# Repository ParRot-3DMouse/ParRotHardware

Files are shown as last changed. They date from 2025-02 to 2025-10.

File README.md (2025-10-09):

## 目次

- [目次](#目次)
- [必要なもの](#必要なもの)
  - [基板](#基板)
  - [3D プリンタ造形部品](#3d-プリンタ造形部品)
  - [実装する部品（電子部品など）](#実装する部品電子部品など)
  - [ケーブル](#ケーブル)
  - [使用する部品（機構部品など）](#使用する部品機構部品など)
  - [そのほか必要なもの](#そのほか必要なもの)
  - [工具](#工具)
- [本体の作成](#本体の作成)
  - [ケーブル加工](#ケーブル加工)
  - [3D プリント造形部品の追加加工](#3d-プリント造形部品の追加加工)
  - [基板のはんだ付け](#基板のはんだ付け)
    - [センサモジュール基板](#センサモジュール基板)
    - [メイン基板](#メイン基板)
    - [サイドキーパッド基板](#サイドキーパッド基板)
    - [親指モジュール基板](#親指モジュール基板)
    - [OLED モジュール基板](#oled-モジュール基板)
    - [追加キーパッドモジュール基板](#追加キーパッドモジュール基板)
    - [メイン基板とサイドキーパッド基板の配線](#メイン基板とサイドキーパッド基板の配線)
  - [組み立て](#組み立て)

## 必要なもの

### 基板

| 名前 | 数  | データへのリンク |
| :--- | :-: | :---: |
| メイン基板 |  1  |  [こちら](https://github.com/ParRot-3DMouse/ParRotHardware/tree/main/1.0/PCB/main)  |
| センサモジュール基板 |  1  | [こちら](https://github.com/ParRot-3DMouse/ParRotHardware/tree/main/1.0/PCB/sensor) |
| サイドキーパッド基板 |  1  |  [こちら](https://github.com/ParRot-3DMouse/ParRotHardware/tree/main/1.0/PCB/side)  |
| OLED モジュール基板 |  1  |  [こちら](https://github.com/ParRot-3DMouse/ParRotHardware/tree/main/1.0/PCB/OLED)  |
| 親指モジュール基板 |  1  | [こちら](https://github.com/ParRot-3DMouse/ParRotHardware/tree/main/1.0/PCB/thumb)  |
| 追加キーパッドモジュール基板 |  1  | [こちら](https://github.com/ParRot-3DMouse/ParRotHardware/tree/main/1.0/PCB/extra)  |

### 3D プリンタ造形部品

| 名前 | 数  | ファイル名 |
| :--- | :-: | :--- |
| 本体底面部 |  1  | bottom.step |
| 本体カバー |  1  | body_cover.step |
| debug カバー |  1  | debug_cover.step |
| OLED モジュールカバー |  1  | OLED_cover.step |
| 親指モジュールカバー |  1  | SW_cover.step |
| ボール保持部 |  1  | ball_holder.step |
| ボール保持部カバー |  1  | ball_holder_cover.step  |
| 追加キーパッドモジュール底面部 |  1  | side_bottom.step |
| 追加キーパッドモジュールカバー |  1  | side_cover.step |
| 親指部キーキャップ 1 |  1  | thumb_keycap1.step |
| 親指部キーキャップ 2 |  1  | thumb_keycap1.step |
| ジョイント |  2  | jount.step |
| (はんだ付け用治具 1) |  1  | はんだ付け用治具 1.step |
| (はんだ付け用治具 2) |  1  | はんだ付け用治具 2.step |

- はんだ付け用治具1,2はメイン基板とサイドキーパッド基板のはんだ付けの際のみに使用します。

### 実装する部品（電子部品など）

| 名前 | 概要 | 数 | 主な調達先 |
| :--- | :--- | :--- | :--- |
| PMW3360 | イメージセンサ | 2 | Aliexpress |
| 1n4148w | 表面実装ダイオード | 11 | 秋月 |
| sk6812MINI-E | マイコン内蔵フルカラー LED | 5 | 秋月 |
| Kailh Swich socket(MX) | CherryMX スイッチのソケット | 9 | 遊舎工房 |
| Kailh Swich socket(Choc) | Choc v1 スイッチのソケット | 2 | 遊舎工房 |
| OLED | 128x32pixcel の SSD1306 登載 OLED モジュール | 1 | 遊舎工房 |
| SKRPABE010 | 表面実装スイッチ | 3 | 秋月 |
| S6B-PH-KL | PH コネクタ ベース付ポスト(サイド型)6 極 | 5 | 千石電商 |
| S8B-PH-KL | PH コネクタ ベース付ポスト(サイド型)8 極 | 1 | 千石電商 |
| B6B-PH-KL | PH コネクタ ベース付ポスト(トップ型)6 極 | 1or2 | 秋月 |
| SKS-01 | ジャンパワイヤ(2.54mm) | 6 | Amazon |
| ピンヘッダ | ハウジング高さ 2.5mm，2.54mm ピッチ，4 ピン  | 1 | (秋月) |

- ピンヘッダは多くの場合、OLEDモジュールに付属しています。  
- デバグ用のSDWを引き出す場合、B6B-PH-KLは2つ使用します。逆にSDWを使用しない場合は1つで問題ありません。

### ケーブル

| 名前 | 概要 | 数量  | 主な調達先 |
| :--- | :--- | :-: | :---: |
| PHR-6 | PH コネクタ　ハウジング 6 極 |  6  | 秋月 |
| PHR-8 | PH コネクタ　ハウジング 8 極 |  1  | 秋月 |
| SPH-002T-P0.5L | PH コネクタ コンタクト | 44  | 秋月 |
|電線 | AGW22 ビニル被膜線 | 1m程度|
- 電線はPHコネクタ用コンタクトに適合する太さのものを選択してください。

### 使用する部品（機構部品など）

| 名前 | 概要 | 数  | 主な調達先 |
| :--- | :--- | :-: | :---: |
| M2 インサートナット | 3.5mm x 4mm(直径 x 高さ) | 12  | [Amazon](https://www.amazon.co.jp/dp/B09NNPNGB8) |
| M2 4mm ネジ | |  6  | |
| M2 6mm ネジ | |  2  | |
| M2 8mm ネジ | |  1  | |
| M2 10mm ネジ | |  2  | |
| M2 20mm ネジ | |  1  | |
| M3 8mm ネジ | |  4  | |
| M3 ナット | |  4  | |
| M3 ワッシャ | |  4  | |
| 磁石 | 直径 6mm 厚み 2.5mm のもの |  4  | セリア |
| ゴム足 | 直径 10mm のもの |  7  | [aitendo](https://www.aitendo.com/product/14406) |

- 記載の寸法の部品の入手が難しい場合、3Dプリント部品を編集し、造形物の寸法を調整することで対処してください。

### そのほか必要なもの
| 名前 | 数 | 主な調達先 |
| :--- | :-: | :---: |
| 40mmトラックボール | 1個 | Amazon |
| CherryMx規格のキーキャップ | 6個 | Amazon、遊舎工房 |

### 工具

ParRot を作成する際に使用した工具を次に示します．

- はんだごて一式
- ピンセット
- ニッパー
- ペンチ
- ワイヤーストリッパ
- PHコネクタ用圧着工具
- 精密ドライバーセット
- ピンバイス
- やすり
- 3D プリンタ

消耗品

- はんだ
- ハンダフラックス
- 接着剤
- マスキングテープ

## 本体の作成

### ケーブル加工

使用するケーブルは次の通りです．

| 番号 | ケーブル本数 | 使用するハウジング | 長さ | 向き |
| :--- | :--- | :--- | :--- | :--- |
| 1 | 6 | 6P | 13mm | 逆 |
| 2 | 6 | 6P | 25mm | 逆 |
| 3 | 6 | 6P | 30mm | 順 |
| 4 | 5 | 8P | 80mm | ー |

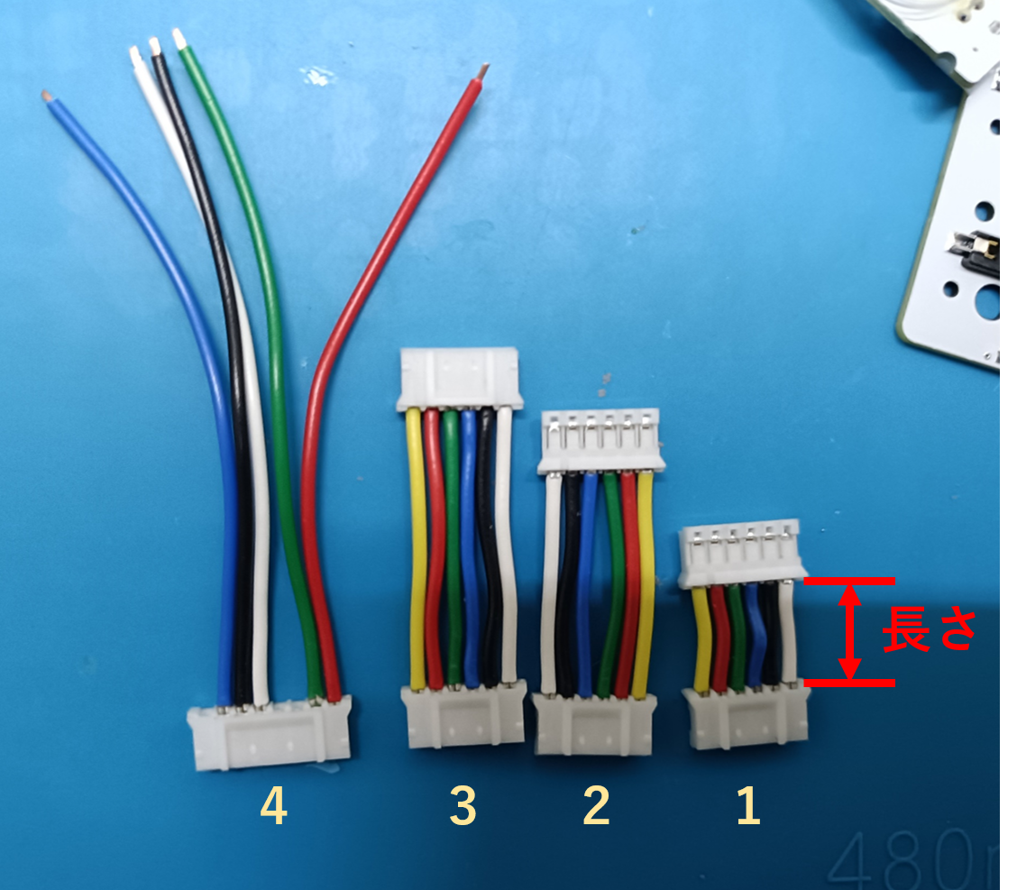
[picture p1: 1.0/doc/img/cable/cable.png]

4 について
コンタクトが見える側で ↓ のようにケーブルを差し込んでください．  
|o|o|-|-|o|o|o|-|

### 3D プリント造形部品の追加加工

必要であればお使いの3Dプリンタに合わせてモデルの各種寸法は元となるstepファイルを編集し、適宜調整してください。
事前にサポート材をすべて除去してください．
また，ピンバイス等を用いてネジを通す穴をネジが通るように加工してください．

1. インサートナットを熱圧入します．
   本体底面部においては次の 8 箇所にインサートナットを圧入します．  
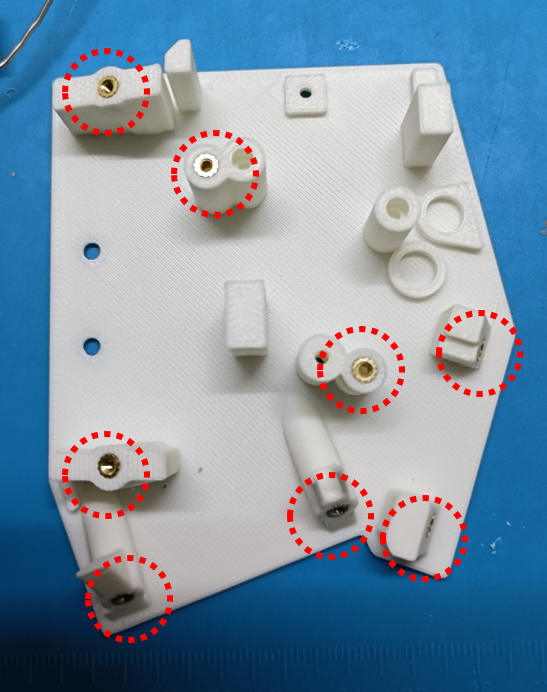
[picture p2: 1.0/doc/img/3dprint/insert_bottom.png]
本体底面部インサートナット
     
   本体カバーにおいては次の 1 箇所にインサートナットを圧入します．  
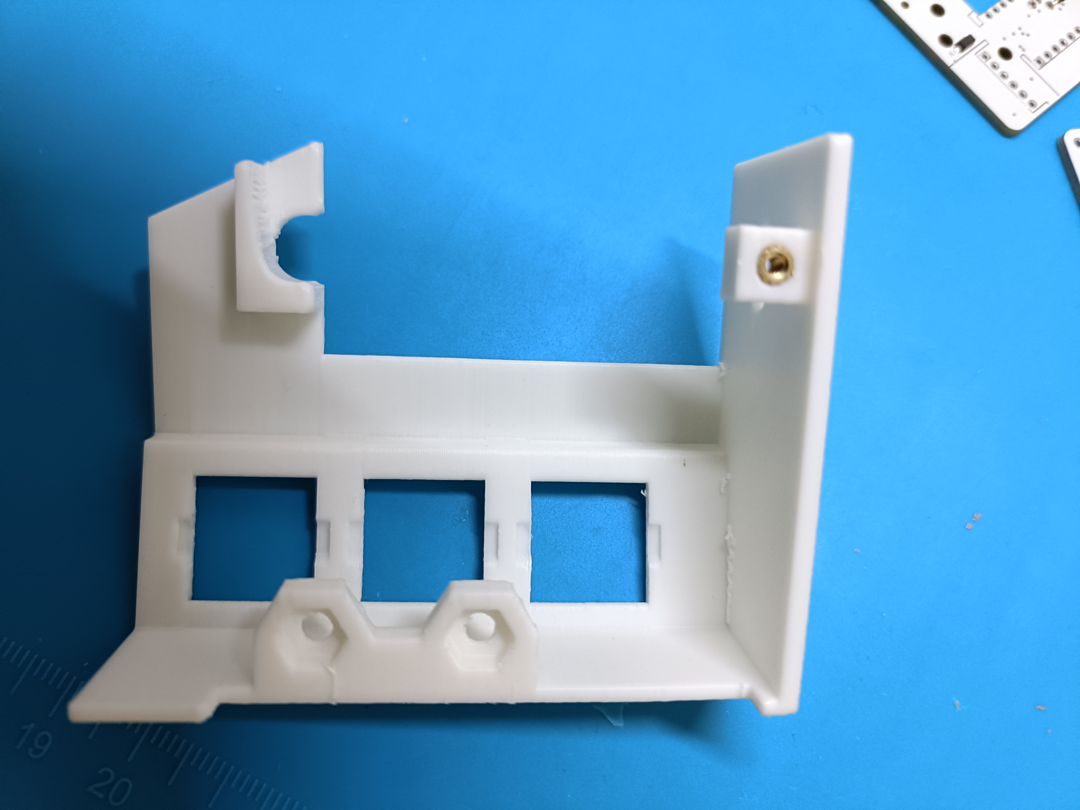
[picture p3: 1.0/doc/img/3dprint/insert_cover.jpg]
本体カバーインサートナット
     
   ボール保持部においては次の 2 箇所にインサートナットを圧入します．  
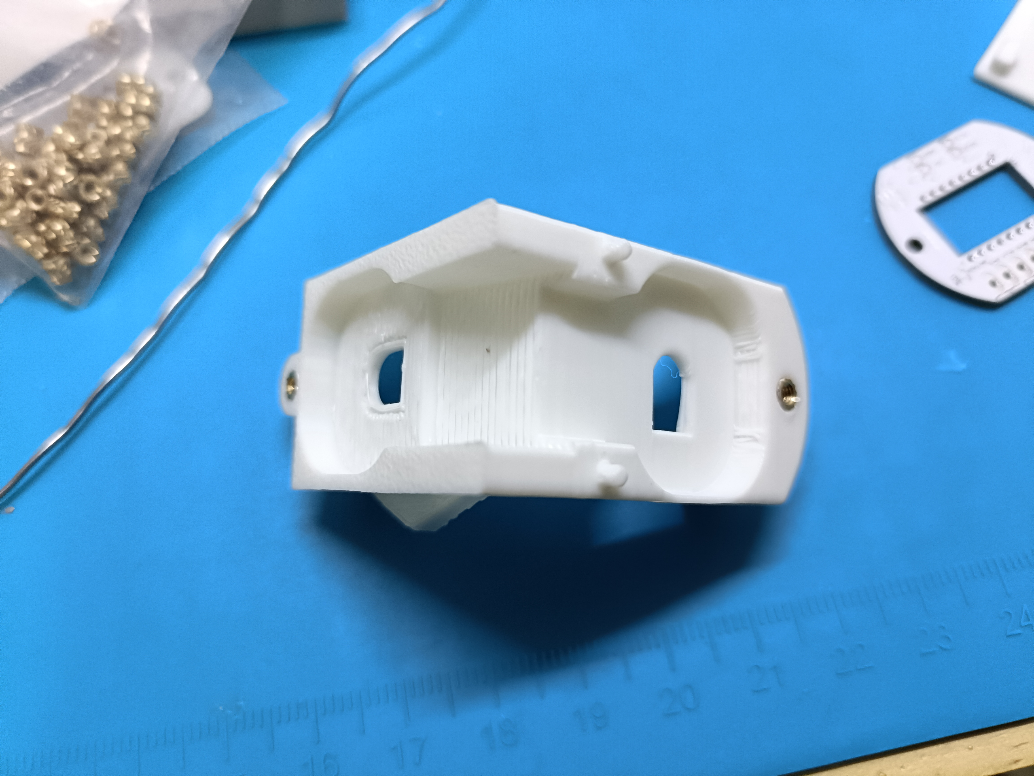
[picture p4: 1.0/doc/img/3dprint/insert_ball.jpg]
ボール保持部インサートナット
     
   追加キーパッドモジュール底面部においては次の 2 箇所にインサートナットを圧入します．  
   追加キーパッドモジュール底面部インサートナット
2. 磁石を接着します．
   本体底面部において，次の二か所に磁石を接着します．
   接着剤を穴の底面と側面に塗布し，磁石を接着します．
   この際に，二つの磁石の極が異なるように配置してください．  
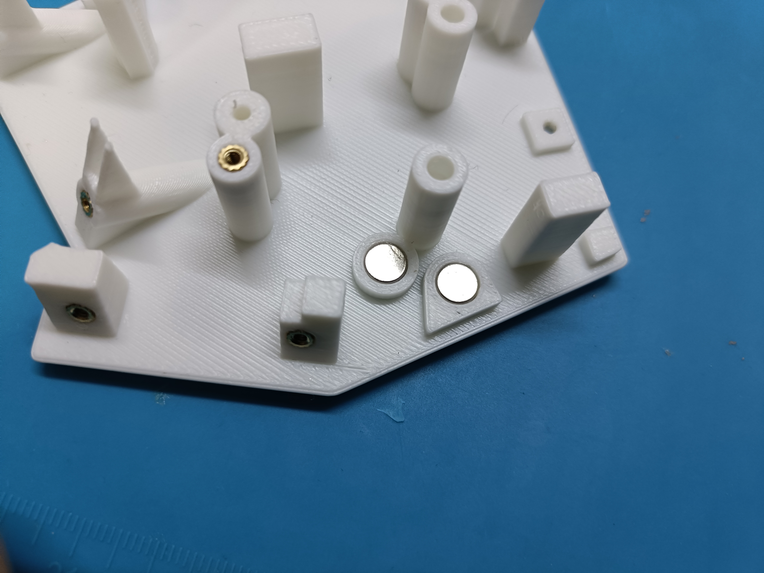
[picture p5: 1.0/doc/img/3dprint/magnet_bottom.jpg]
本体底面部磁石
   

debug カバーにおいて次の二か所に磁石を接着します．
この際に，本体底面部と引き合う向きで磁石を接着します．
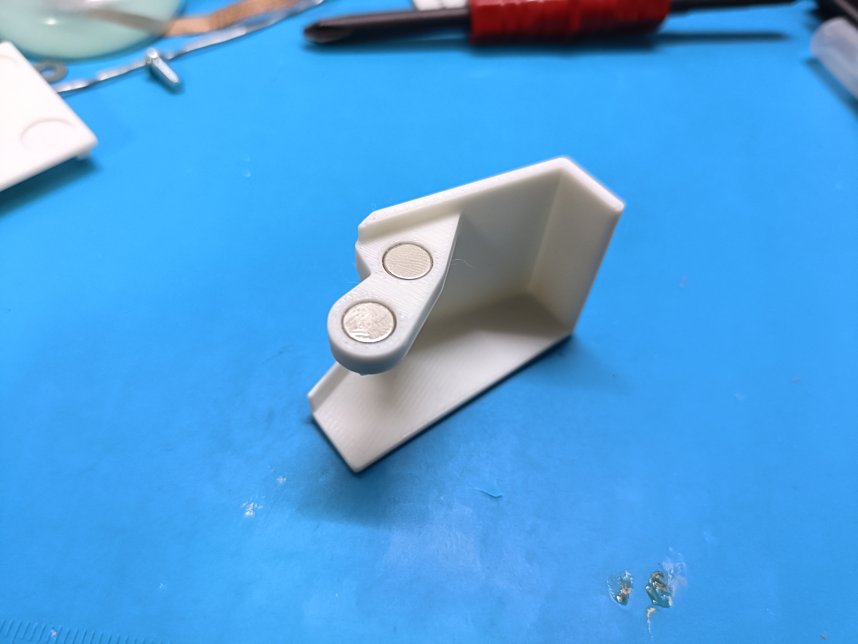
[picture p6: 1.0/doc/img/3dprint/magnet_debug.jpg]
debugカバー磁石


3. ゴム足を取り付けます．
   本体底面部，追加キーパッドモジュール底面部にゴム足を接着します．
   くぼみがあるところにゴム足を接着します．
   ゴム足がはがれることが多かったので接着剤を使用することを推奨します．
   本体底面部ゴム足
   追加キーパッドモジュール底面部ゴム足

### 基板のはんだ付け

#### センサモジュール基板

表面  
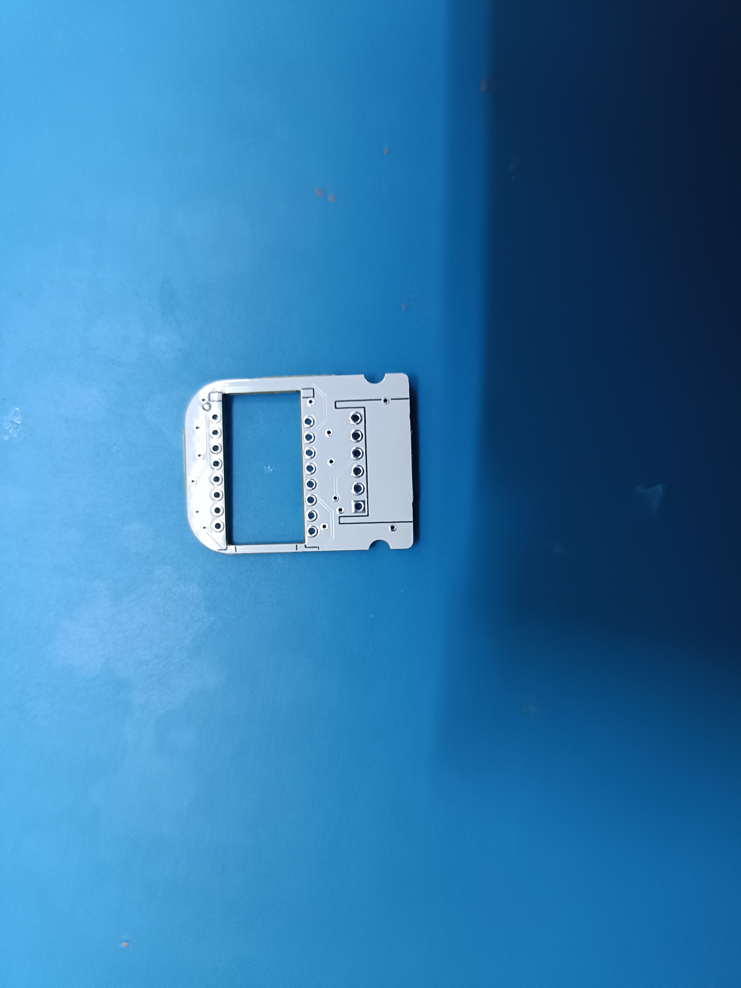
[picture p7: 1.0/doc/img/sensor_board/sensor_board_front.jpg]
センサ基板表面
  
裏面  
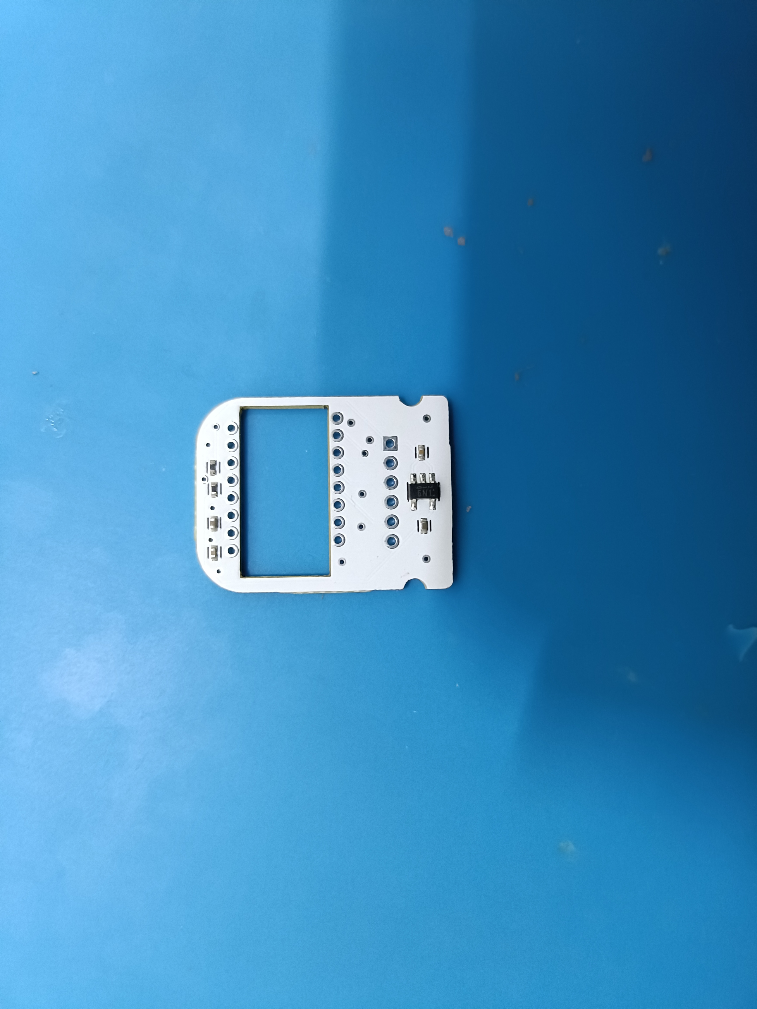
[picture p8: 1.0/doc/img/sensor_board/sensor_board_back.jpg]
センサ基板裏面


センサ基板に実装する部品は次の通りです．

| 名前 | 概要 | 数  |
| :--- | :--- | :-- |
| PMW3360 | イメージセンサ | 1 |
| S6B-PH-KL | PH コネクタ ベース付ポスト(サイド型)6 極 | 1 |

1. PMW3360 の実装
   PMW3360 を実装します．向きに注意してください．正しい向きは．画像を参照してください。裏面からセンサを基板に差し込み，表面ではんだ付けします．  
   センサ基板PMW3360実装裏  
   センサ基板PMW3360実装表

2. コネクタの実装
   次に，コネクタを実装します．
   裏面からコネクタを基板に差し込み，表面ではんだ付けします．  
   センサ基板コネクタ実装
3. レンズの取り付け
   PMW3360 のレンズを取り付けます．  
   センサのカプトンテープを剥がし，レンズをセンサに取り付けます．  
   センサ基板レンズ取り付け  
   センサから飛び出ているガイドポスト二か所を半田ごてで溶かし，レンズを固定します．  
   センサ基板レンズ固定

#### メイン基板

表面  
メイン基板表面  
裏面  
メイン基板裏面

メイン基板に実装する部品は次の通りです．

| 名前 | 概要 | 数 |
| :--- | :--- | :----- |
| PMW3360 | イメージセンサ | 1 |
| SKRPABE010 | 表面実装スイッチ | 2 |
| S6B-PH-KL  | PH コネクタ ベース付ポスト(サイド型)6 極 | 2 |
| S8B-PH-KL  | PH コネクタ ベース付ポスト(サイド型)8 極 | 1 |
| B6B-PH-KL  | PH コネクタ ベース付ポスト(トップ型)6 極 | 1 or 2 |

1. スイッチの実装
   Boot スイッチと Reset スイッチを実装します．SKRPABE010 を表面に実装します．  
   メイン基板スイッチ実装

2. PMW3360 の実装
   次に，PMW3360 を実装します．表面で足をはんだ付けします．向きに注意してください．向きを基板裏面のシンボルに合わせます．裏面からセンサを基板に差し込み，表面ではんだ付けします．  
   メイン基板PMW3360実装表  
   メイン基板PMW3360実装裏

3. コネクタの実装
次に，コネクタを実装していきます．  
初めに，センサモジュールとの接続用のコネクタ(S6B-PH-KL)を実装します.
表面からコネクタを基板に差し込み，裏面ではんだ付けします．  
メイン基板センサコネクタ実装  
次に，サイドキーパッドとの接続用のコネクタ(S8B-PH-KL)と OLED モジュールとの接続コネクタ(S6B-PH-KL)を実装します．裏面からコネクタを基板に差し込み，表面ではんだ付けします．  
メイン基板サイドOLEDコネクタ実装  
次に，親指モジュールとの接続用のコネクタ(B6B-PH-KL)を実装します．裏面からコネクタを基板に差し込み，表面ではんだ付けします．  
メイン基板親指コネクタ実装  
任意でデバッグ用のコネクタを実装します．表面からコネクタを基板に差し込み，裏面ではんだ付けします．
<!--
![メイン基板デバグコネクタ実装](1.0/doc/img/main_board/conn_debug.jpg)
-->

4. レンズの取り付け
   センサ基板と同様の手順で PMW3360 のレンズを取り付けます．

#### サイドキーパッド基板

表面  
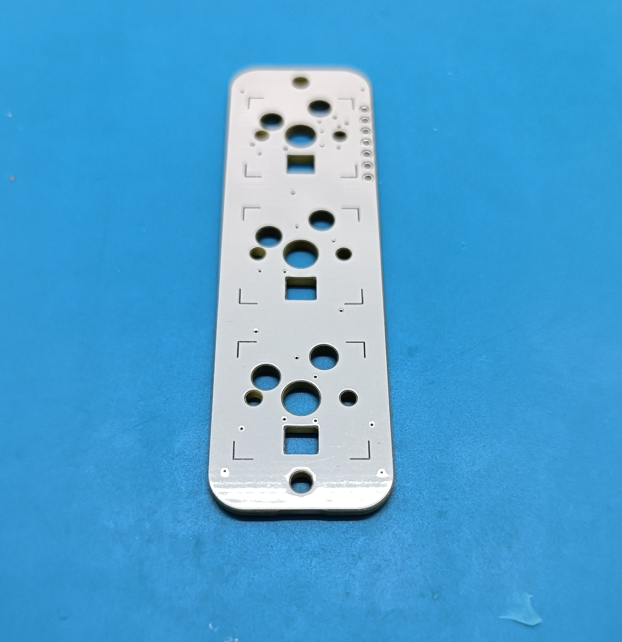
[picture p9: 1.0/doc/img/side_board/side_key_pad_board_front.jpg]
サイドキーパッド基板表面
  
裏面  
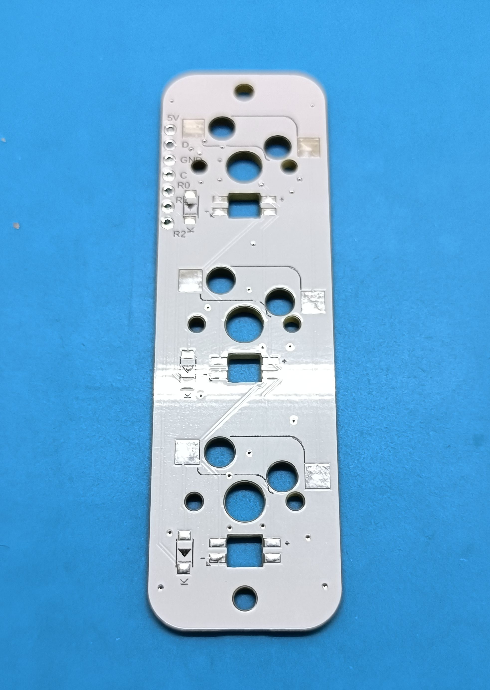
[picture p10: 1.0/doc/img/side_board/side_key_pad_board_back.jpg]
サイドキーパッド基板裏面


実装する部品は次の通りです．
| 名前 | 概要 | 数 |
|:-|:-|:-|
| Kailh Swich socket(MX) | CherryMX スイッチのソケット | 3 |
| sk6812MINI-E | マイコン内蔵フルカラー LED | 3 |
| 1n4148w | 表面実装ダイオード | 3 |

裏面に部品を実装します．
LED,ダイオード，MX ソケットを実装します．LED，ダイオード実装の際には向きに注意してください．正しい向きは画像を参照してください．  
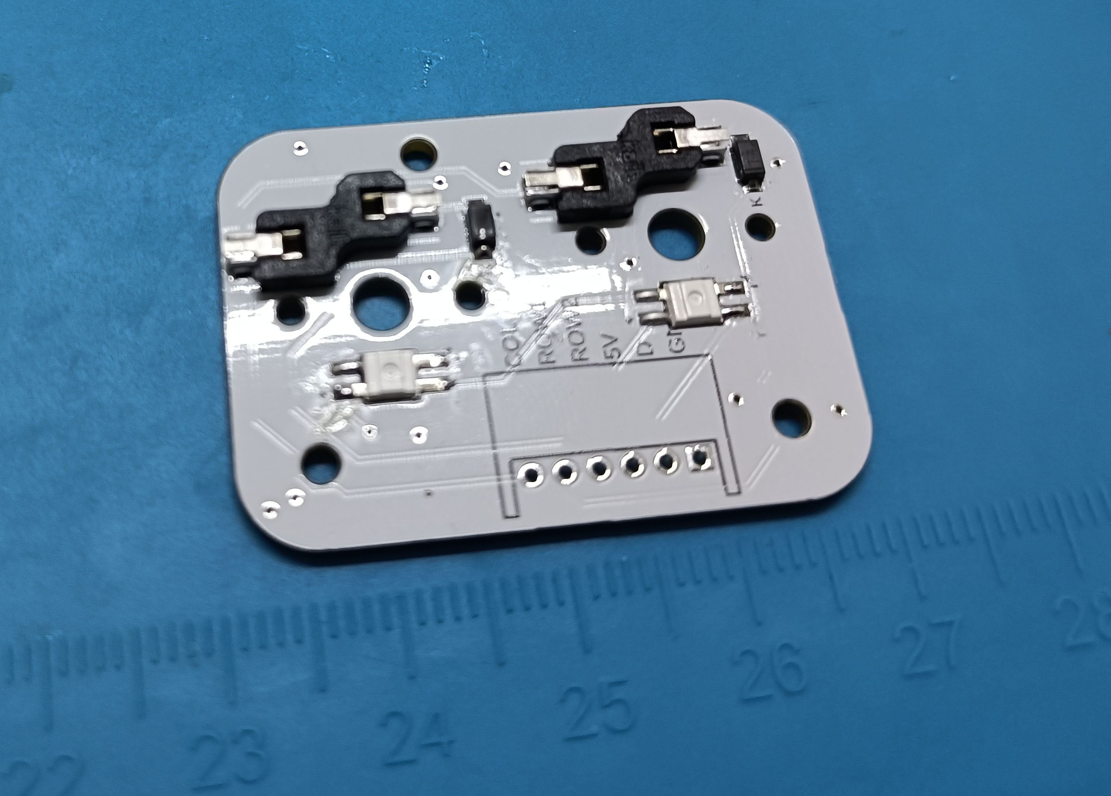
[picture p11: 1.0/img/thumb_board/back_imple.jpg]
サイドキーパッド基板裏面実装
  
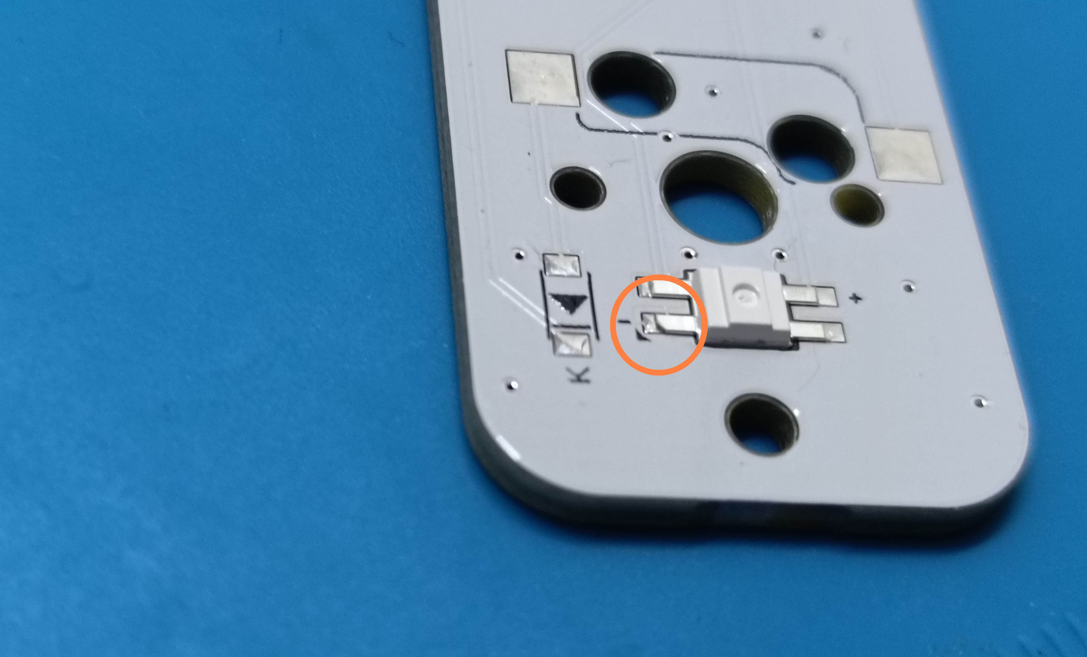
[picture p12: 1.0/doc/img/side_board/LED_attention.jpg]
RGBLED注意
  
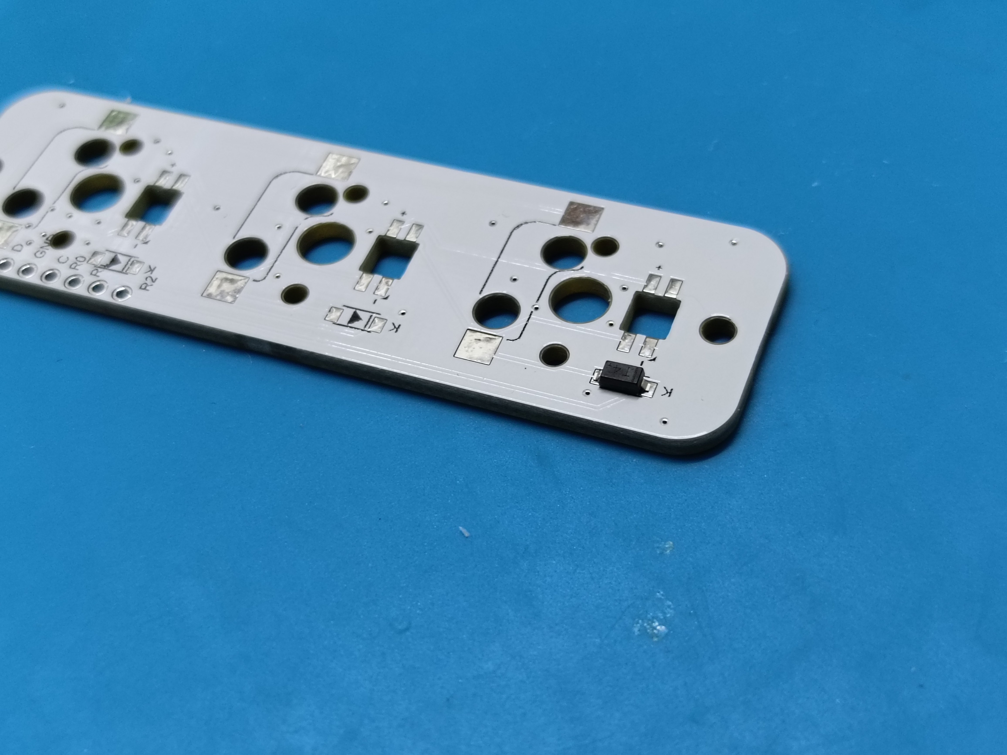
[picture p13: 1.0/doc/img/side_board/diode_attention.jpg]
ダイオード注意


#### 親指モジュール基板

表面  
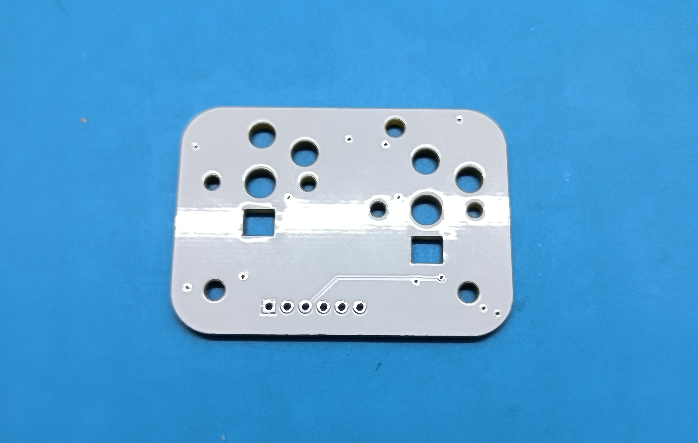
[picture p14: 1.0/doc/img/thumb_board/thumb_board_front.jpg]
親指モジュール基板表面
  
裏面  
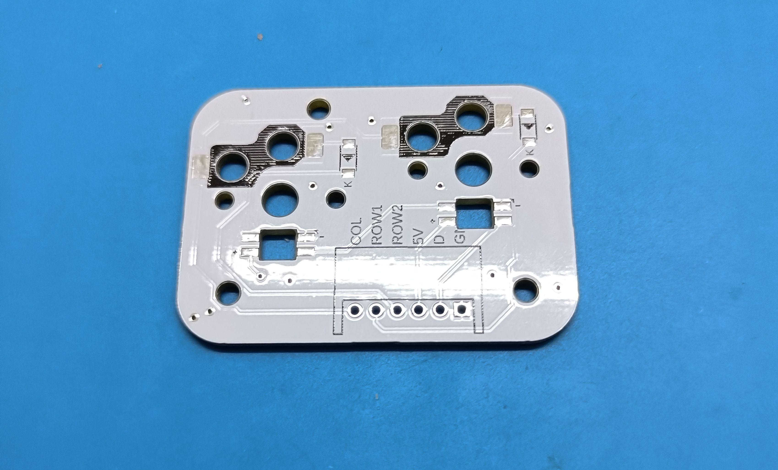
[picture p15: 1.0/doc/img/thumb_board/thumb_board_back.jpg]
親指モジュール基板裏面


実装する部品は次の通りです．
| 名前 | 概要 | 数 |
|:-|:-|:-|
| Kailh Swich socket(Choc) | Kailh_choc v1 スイッチのソケット | 2 |
| sk6812MINI-E | マイコン内蔵フルカラー LED | 2 |
| 1n4148w | 表面実装ダイオード | 2 |
| S6B-PH-KL | PH コネクタ ベース付ポスト(サイド型)6 極 | 1 |

裏面に部品を実装します．
LED,ダイオード，choc ソケットを実装します．choc ソケット，LED，ダイオード実装の際には向きに注意してください．
choc ソケットにも向きがあります．図のように飛び出している部分が外側を向くように実装します．  
親指モジュール基板裏面実装  
RGBLED注意

接続用のコネクタを実装します．裏面からコネクタを基板に差し込み，表面ではんだ付けします．  
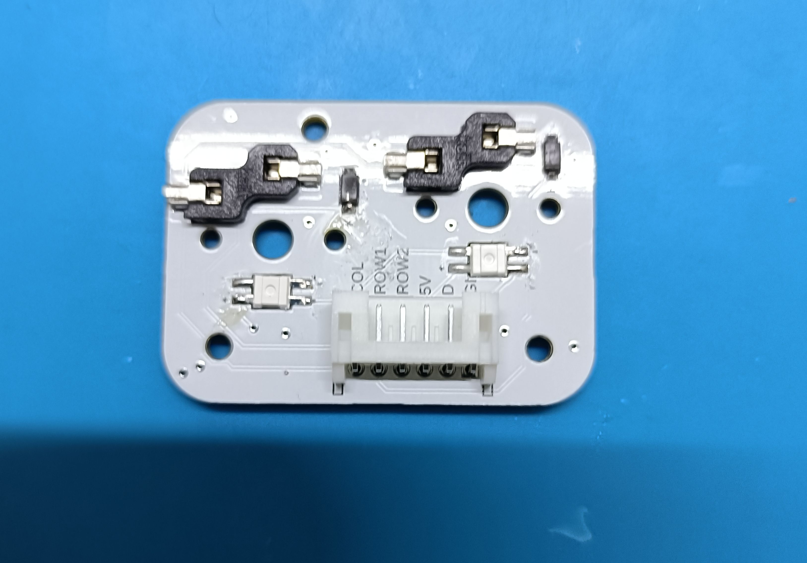
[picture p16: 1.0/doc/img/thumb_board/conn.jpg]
親指モジュール基板コネクタ実装


#### OLED モジュール基板

表面  
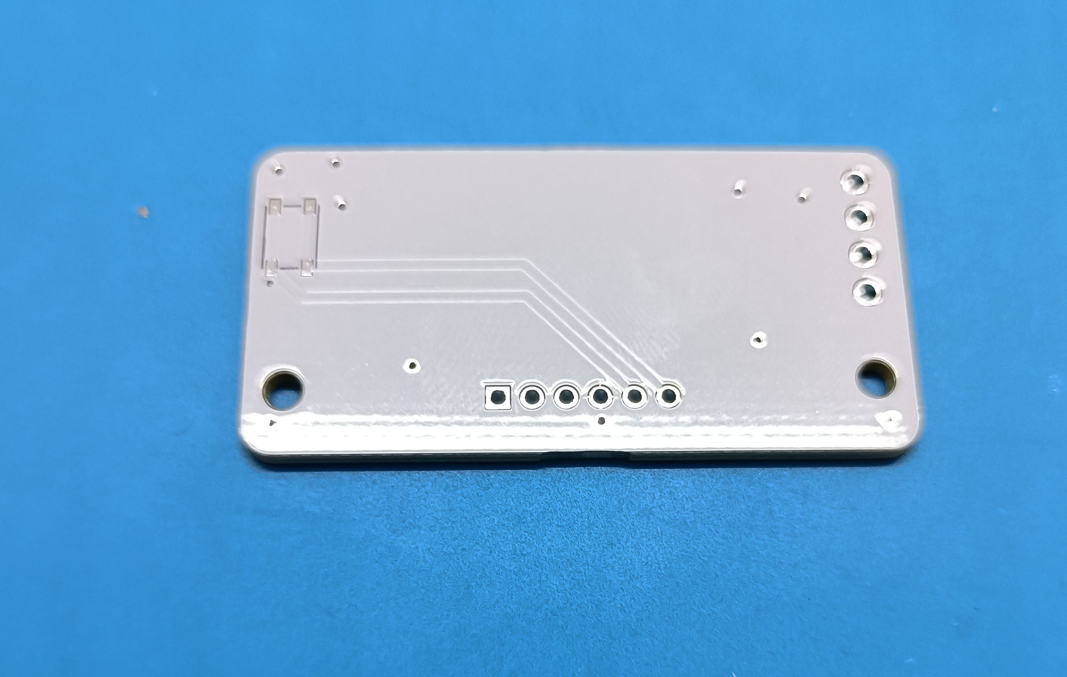
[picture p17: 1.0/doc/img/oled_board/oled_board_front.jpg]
OLEDモジュール基板表面
  
裏面  
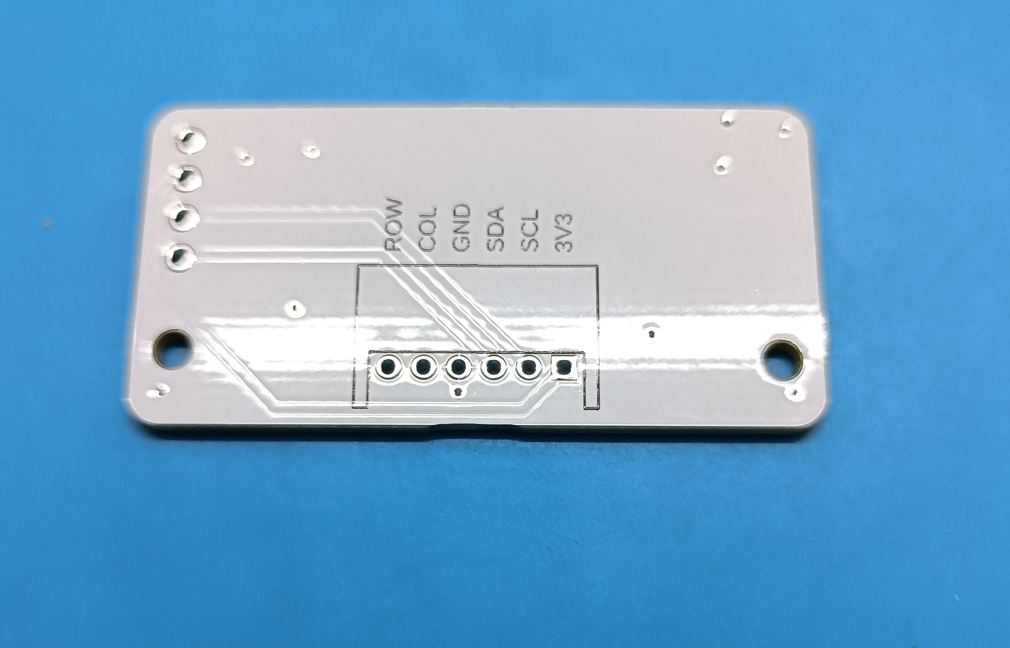
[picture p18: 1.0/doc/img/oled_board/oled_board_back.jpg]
OLEDモジュール基板裏面


実装する部品は次の通りです．
| 名前 | 概要 | 数 |
|:-|:-|:-|
| SKRPABE010 | 表面実装スイッチ | 1 |
| OLED | 128x32pixcel の SSD1306 登載 OLED モジュール| 1 |
| S6B-PH-KL | PH コネクタ ベース付ポスト(サイド型)6 極 | 1 |

1. スイッチの実装
   表面実装スイッチを表面に実装します．  
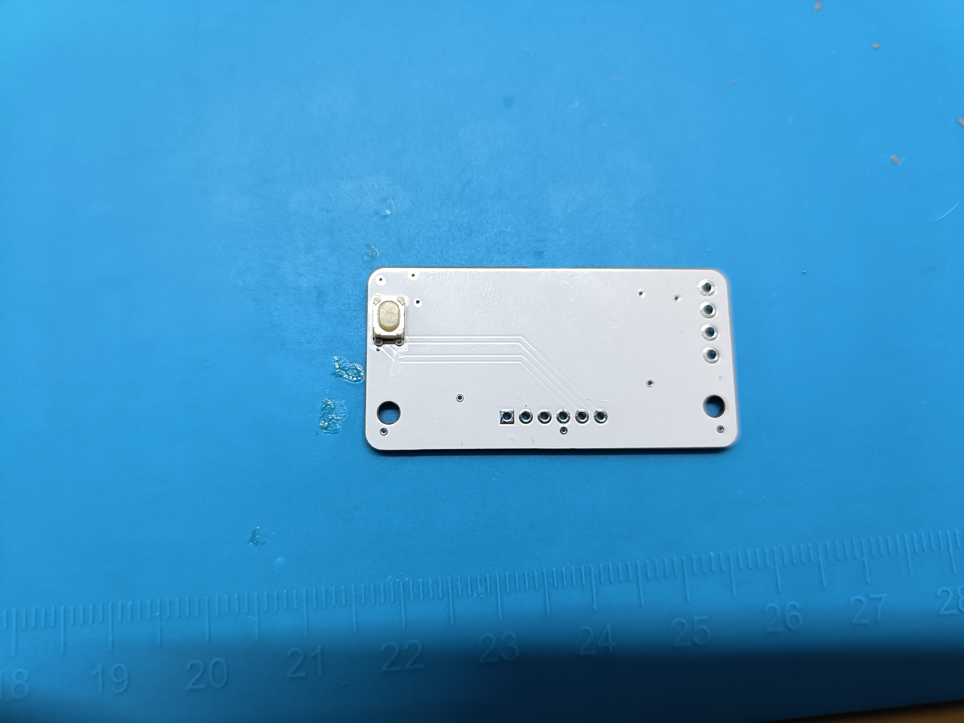
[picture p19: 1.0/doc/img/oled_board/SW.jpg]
OLEDモジュール基板表面実装
   

2. コネクタの実装
   次に，コネクタを実装します．裏面からコネクタを基板に差し込み，表面ではんだ付けします．  
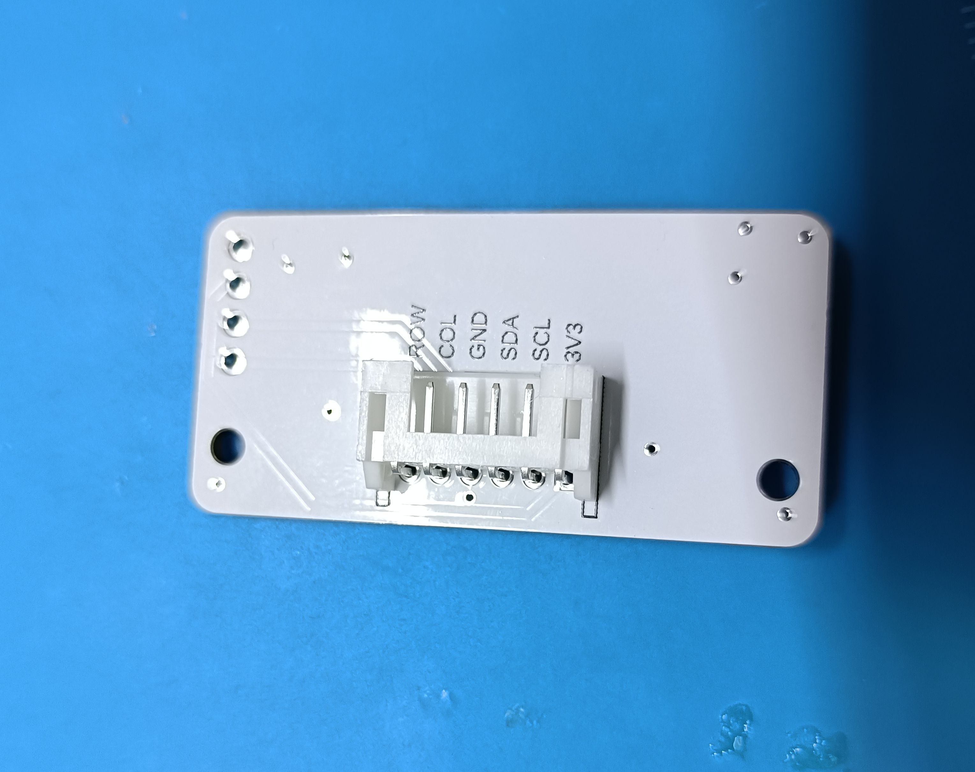
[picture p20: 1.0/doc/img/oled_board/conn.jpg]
OLEDモジュール基板コネクタ実装
   

3. OLED の実装
   次に，OLED を実装します．  
   OLED にピンヘッダをはんだ付けします．  
   OLEDピンヘッダはんだ付け  
   OLED を基板に差し込みます．任意で基板の裏側から出ているピンヘッダを切断します．  
   基板の裏側からピンヘッダをはんだ付けします．この際に基板のエッジと OLED のエッジが平行になるように注意してください．大きくゆがんでいると組み立てた際に OLED の押し込みができなくなる場合があります．  
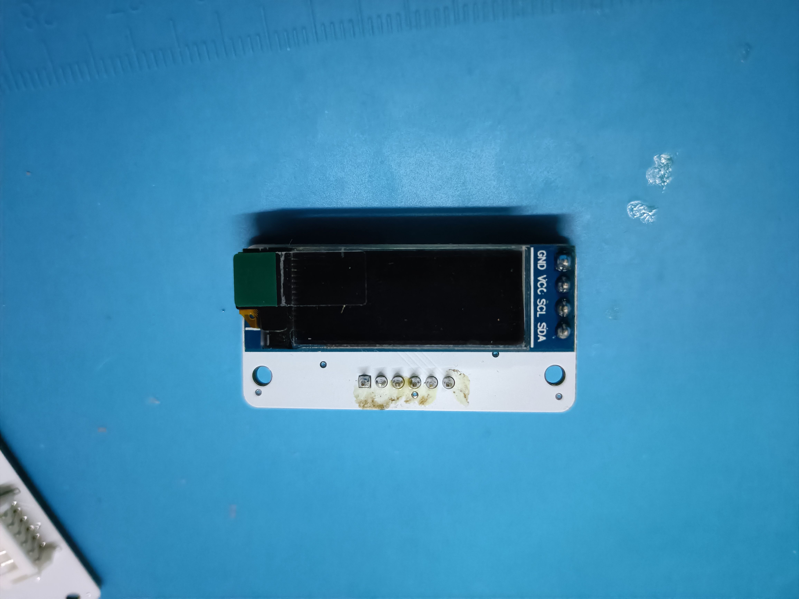
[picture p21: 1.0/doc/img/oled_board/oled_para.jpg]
OLED注意
   

#### 追加キーパッドモジュール基板

表面  
追加キーパッドモジュール基板表面  
裏面  
追加キーパッドモジュール基板裏面

実装する部品は次の通りです．
| 名前 | 概要 | 数 |
|:-|:-|:-|
|| CherryMX スイッチのソケット | 6 |
| 1n4148w | 表面実装ダイオード | 6 |

1. 表面実装部品の実装
   裏面に部品を実装します．
   ダイオード，MX ソケットを実装します．ダイオード実装の際には向きに注意してください．図のように基板のシルクに合わせて実装します．  
   追加キーパッドモジュール基板裏面実装  
   ダイオード注意

2. ケーブルの取り付け
   ケーブル 4 をはんだ付けします．ケーブルの向きに注意してください．ケーブルが外側を向きようにします．また，基板を裏面から見た際にハウジングが見える向きにします．  
   追加キーパッドモジュール基板ケーブル4

ケーブルを反対側に折り曲げます．  
追加キーパッドモジュール基板ケーブル4折り曲げ

#### メイン基板とサイドキーパッド基板の配線

メイン基板とサイドキーパッド基板を接続します．
本体底面部にメイン基板とサイドキーパッド基板を取り付けます．固定には M2 4mm ネジを 4 本使用します．  
メイン基板サイドキーパッド基板取り付け  
ジャンパワイヤを 7 本基板表側から差し込みます．  
メイン基板サイドキーパッド基板配線  
この状態でマスキングテープ等で固定します．  
メイン基板サイドキーパッド基板配線  
メイン基板とサイドキーパッド基板を外し，はんだ付け用治具 1,2 に取り付けます．  
メイン基板サイドキーパッド基板配線  
基板の裏側からジャンパワイヤをはんだ付けします．  
メイン基板サイドキーパッド基板配線  
余分なジャンパワイヤを切断します．  
メイン基板サイドキーパッド基板配線

### 組み立て

追加キーパッドモジュール底面部にジョイントを取り付けます．ねじは M3 8mm ネジを使用します．また，ジョイントの上下を M3 ワッシャで挟み，M3 ナットで締結します．  
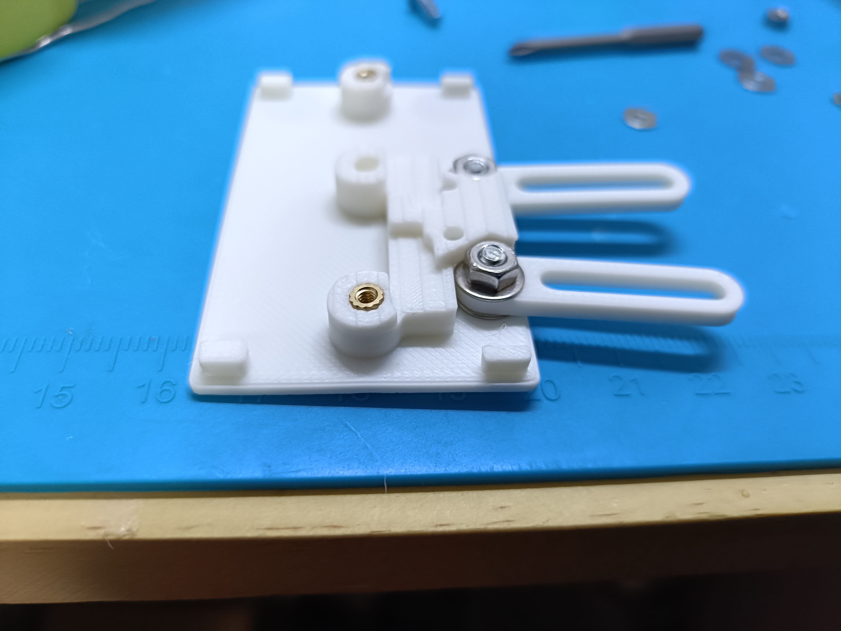
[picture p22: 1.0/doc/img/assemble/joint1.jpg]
  
本体底面部とジョイントを締結します．ねじは M3 8mm ネジを使用します．また，ジョイントの上下を M3 ワッシャで挟み，M3 ナットで締結します．  
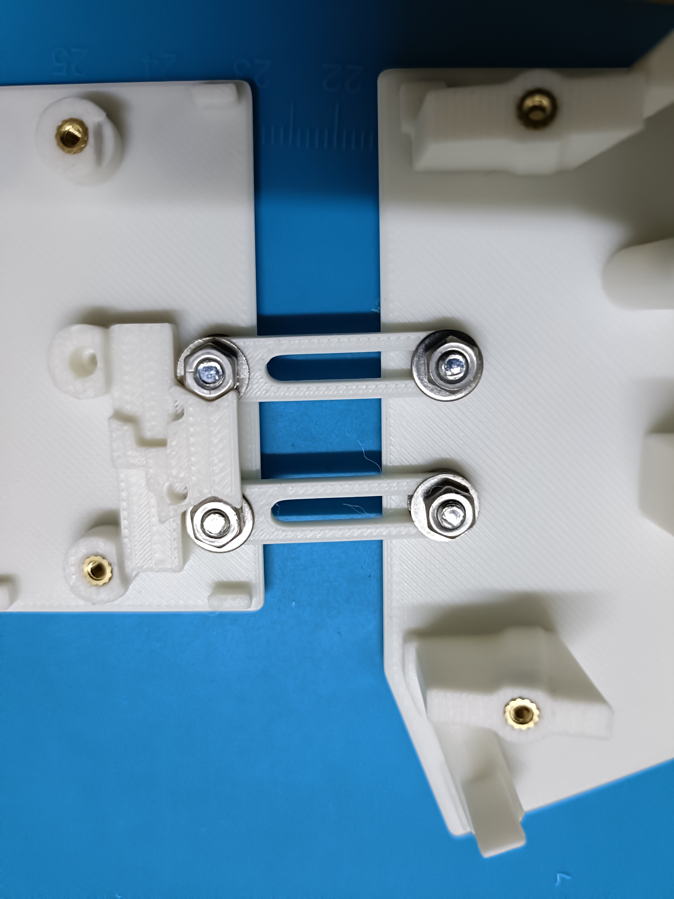
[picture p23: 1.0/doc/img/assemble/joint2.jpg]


基板をケーブルで接続します．  
使用するケーブルは次の通りです．

- メイン基板 - センサモジュール基板  
  &rarr;ケーブル 1
- メイン基板 - 親指モジュール基板  
  &rarr;ケーブル 2
- メイン基板 - OLED モジュール基板  
  &rarr;ケーブル 3

また，メイン基板とサイドキーパッド基板の接続も行います．
基板接続

基板を本体底面部，追加キーパッドモジュール底面部にに取り付けます．
締結には M2 4mm ネジを使用します．締結箇所は次の 6 箇所です．
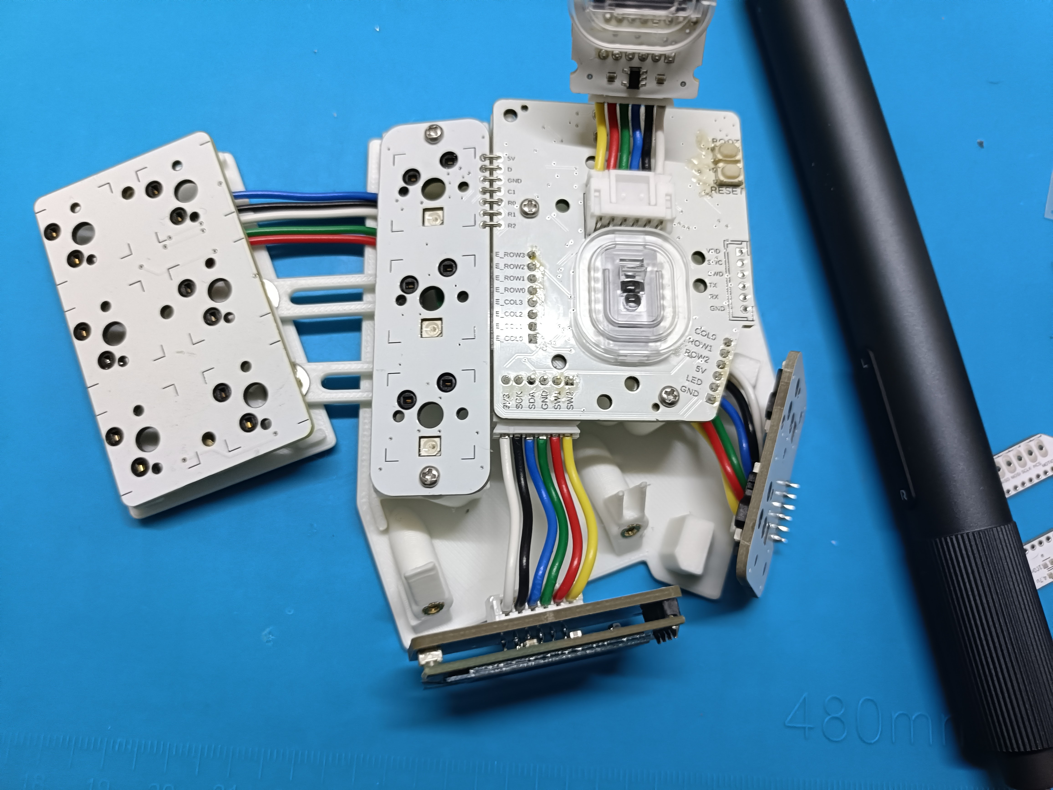
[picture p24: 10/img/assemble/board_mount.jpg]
基板取り付け


本体カバーを取り付けます．
この際に M3 ナットの向きを調整してください．
本体カバー取り付け

ボール保持部，ボール保持部カバーを取り付けます．
ボール保持部取り付け

ねじで締結します．

| 番号 | 使用するねじ |
| :--: | :--- |
|  1 | M2 8mm ネジ  |
|  2 | M2 10mm ネジ |
|  3 | M2 20mm ネジ |

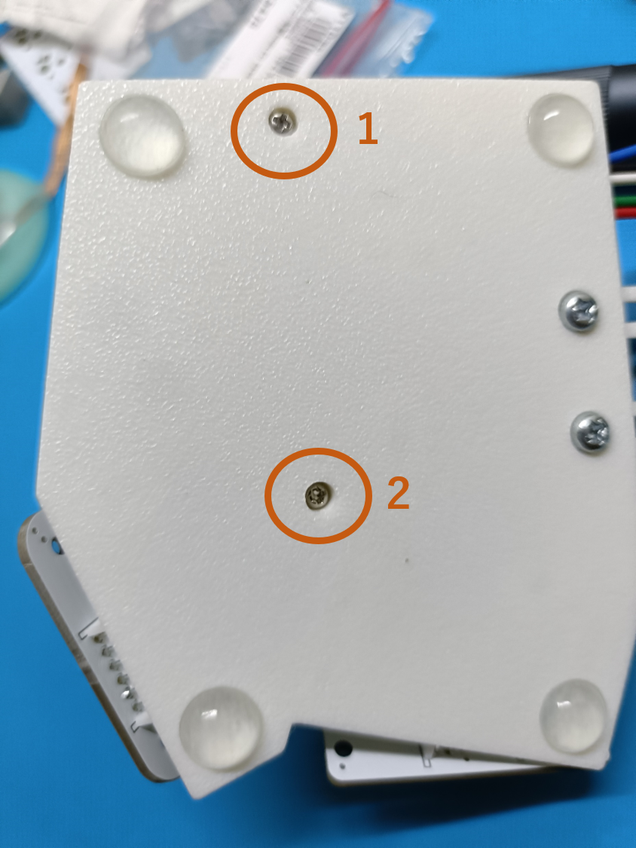
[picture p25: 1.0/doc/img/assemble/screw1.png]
ねじ締結場所1
  
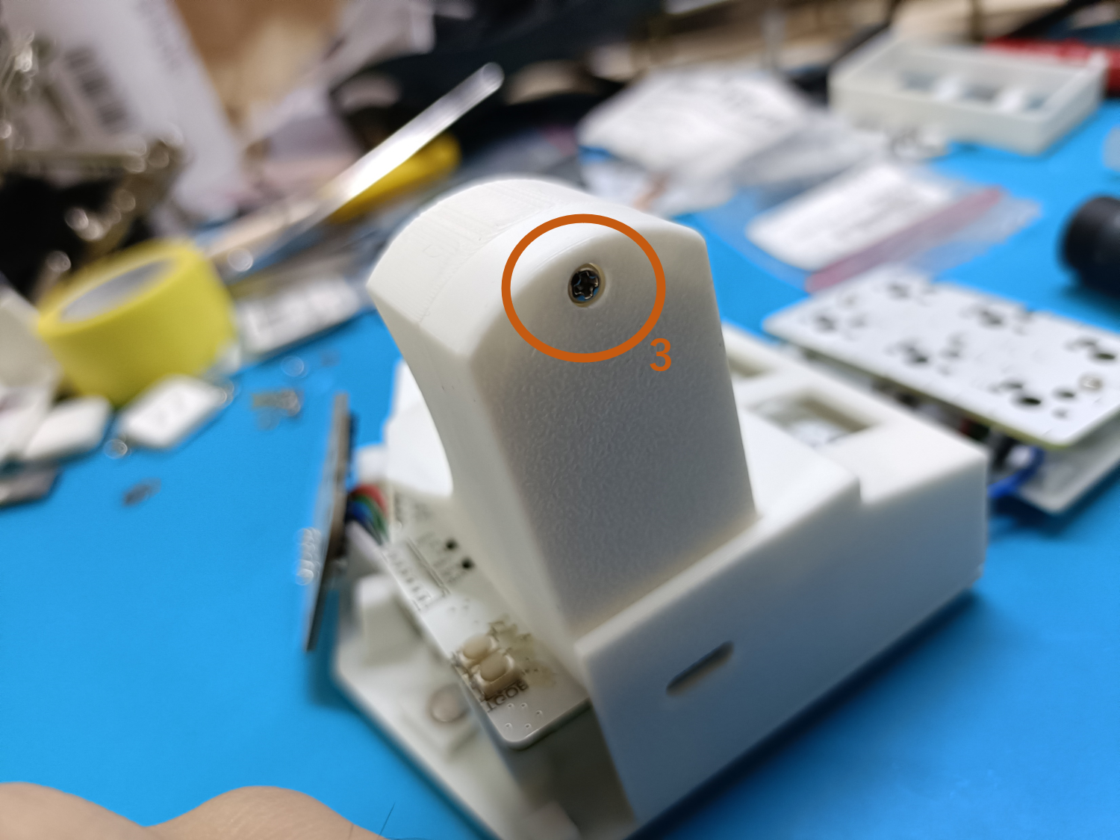
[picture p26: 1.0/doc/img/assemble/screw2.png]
ねじ締結場所2


OLED モジュールカバーを取り付けます．締結には M2 8mm ネジを使用します．  
OLEDモジュールカバー取り付け

親指モジュールカバーを取り付けます．締結には M2 6mm ネジを使用します．  
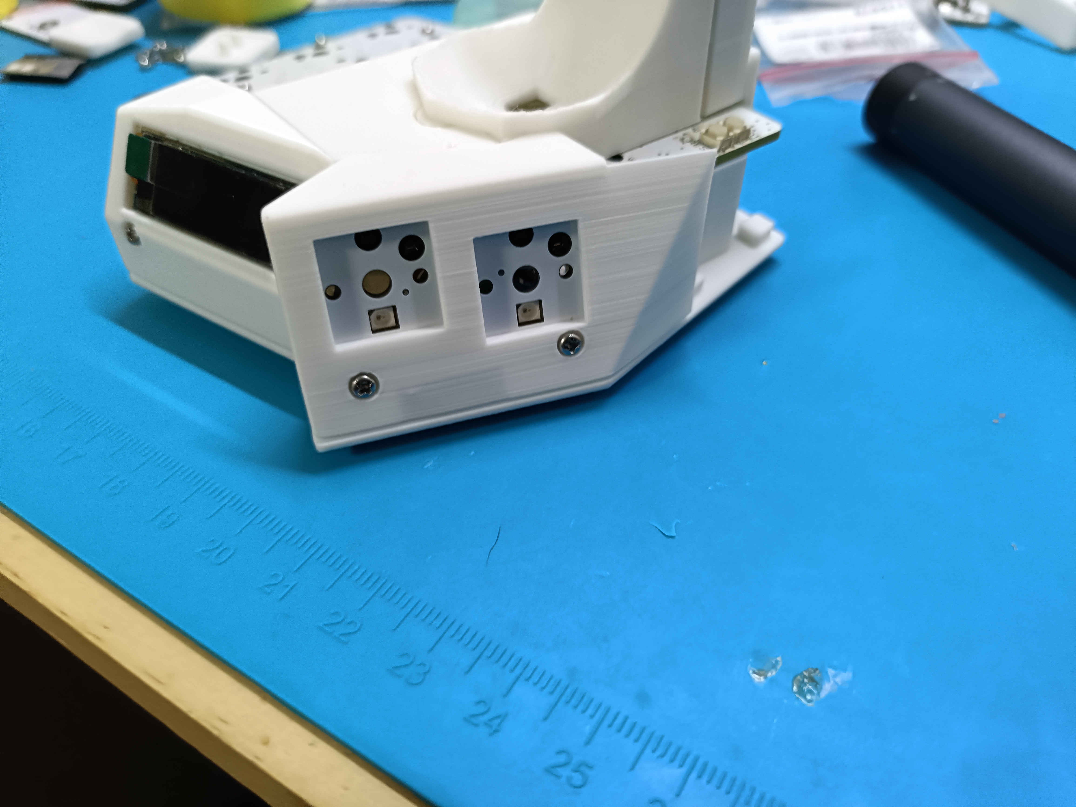
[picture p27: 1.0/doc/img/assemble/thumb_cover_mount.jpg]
親指モジュールカバー取り付け


サイドキーパッドカバーを取り付けます．  
サイドキーパッドカバー取り付け

キースイッチを取り付けます．  
キースイッチ取り付け

キーキャップを取り付けます．  
キーキャップ取り付け

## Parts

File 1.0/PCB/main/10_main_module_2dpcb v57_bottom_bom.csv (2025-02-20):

Comment | Designator | Footprint | LCSC Part #
1k | R5 R9 R10 | RESC1005X40 | C11702
1u | C4 C9 C21 | CAPC1005X60 | C52923
4.7u | C1 | CAPC1005X60 | C23733
5.1k | R3 R4 | RESC1005X40 | C25905
10k | R2 R6 R11 R12 R13 R14 R15 | RESC1005X40 | C25744
10u | C5 C6 | CAPC1005X60 | C15525
27 | R7 R8 | RESC1005X40 | C25100
27p | C19 C20 | CAPC1005X60 | C1557
39 | R1 | RESC1005X40 | C25110
100n | C2 C3 C10 C11 C12 C13 C14 C15 C16 C17 C18 C22 C23 C24 | CAPC1005X60 | C1525
AMS1117-3.3 | U4 | SOT229P700X180-4N | C6186
BSS138 | Q1 Q2 | SOT95P240X111-3N | C2938375
LED_RED | LED0 | LEDC1608X65N_RND | C2290
RP2040 | U3 | QFN40P700X700X90-57N | C2040
TCR2EF19 | U2 | SC-74A SOT-753 | C146366
TYPE-C-31-M-12 | J1 | HRO_TYPE-C-31-M-12 | C165948
W25Q128JVSIQ | U5 | SOIC127P790X216-8N | C97521
X322512MSB4SI | Y1 | OSC_X322516MLB4SI | C9002
1n4148 | D3 | SOD-123 | C81598
B5819W SL | SD1 | SOD-123 | C8598

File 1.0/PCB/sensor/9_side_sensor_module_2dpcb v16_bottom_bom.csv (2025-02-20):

Comment | Designator | Footprint | LCSC Part #
1u | C4 | CAPC1005X60 | C52923
4.7u | C1 | CAPC1005X60 | C23733
10k | R2 | RESC1005X40 | C4109
39 | R1 | RESC1005X40 | C25110
100n | C2 C3 | CAPC1005X60 | C1525
TCR2EF19TCR2EF19 | U2 | SC-74A SOT-753 | C146366

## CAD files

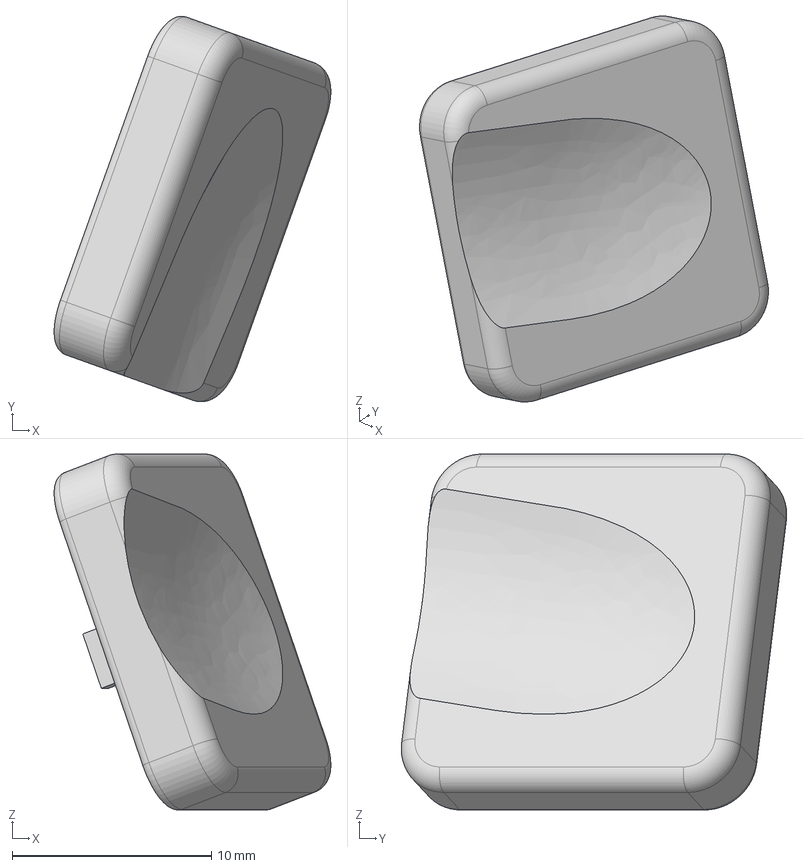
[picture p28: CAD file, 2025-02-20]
1.0/step/thumb_keycap1.step
13.9 x 19.3 x 17.9 mm

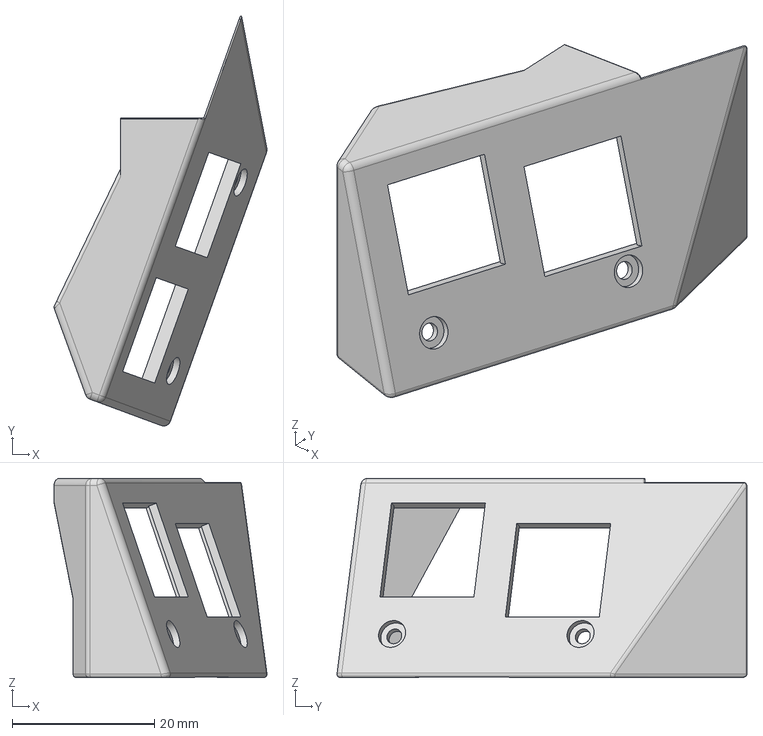
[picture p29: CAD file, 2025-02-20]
1.0/step/SW_cover.step
29.9 x 57.5 x 28.0 mm

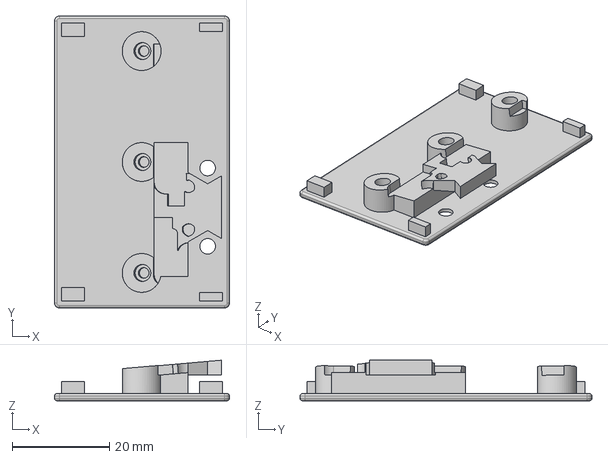
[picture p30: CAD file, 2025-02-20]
1.0/step/side_bottom.step
36.1 x 60.1 x 8.37 mm

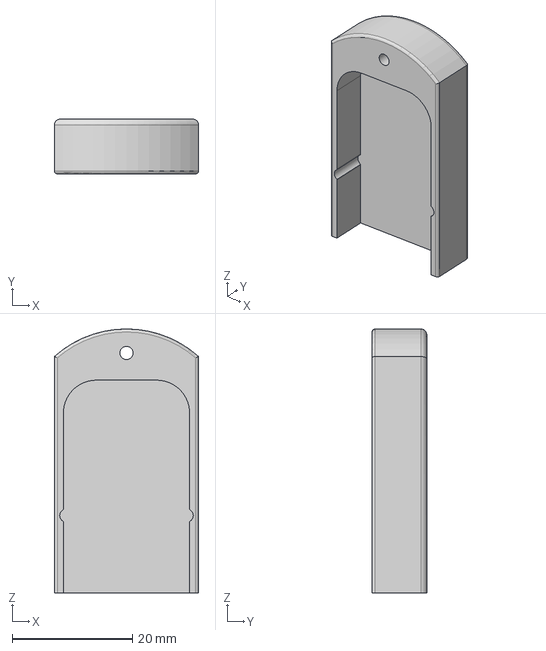
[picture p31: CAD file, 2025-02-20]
1.0/step/ball_holder_cover.step
24.0 x 9.11 x 43.9 mm

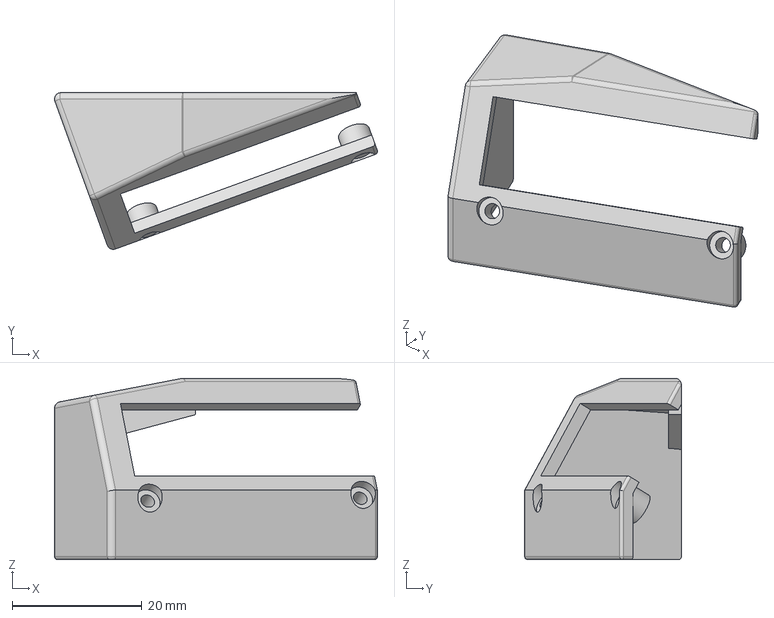
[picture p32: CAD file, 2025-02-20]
1.0/step/OLED_cover.step
49.8 x 24.2 x 28.0 mm

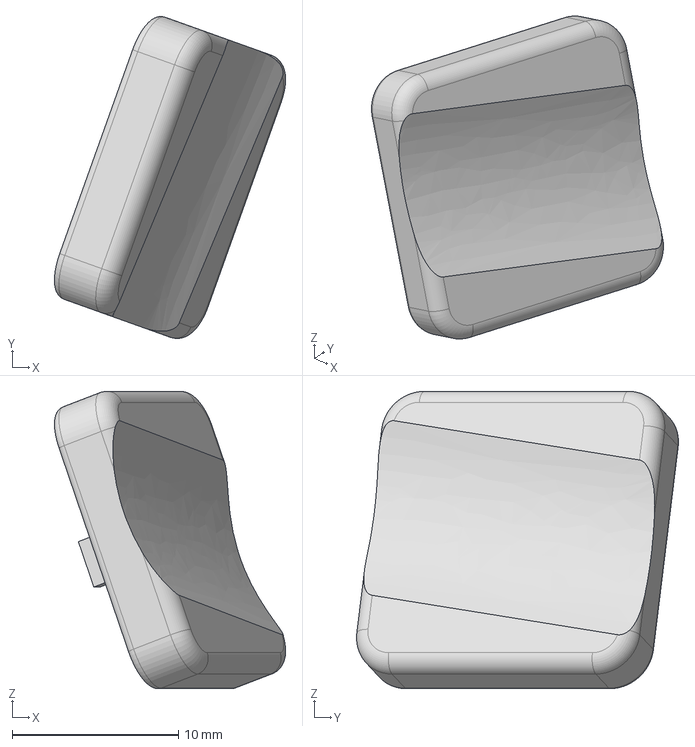
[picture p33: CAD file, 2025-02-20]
1.0/step/thumb_keycap2.step
13.9 x 19.3 x 17.9 mm

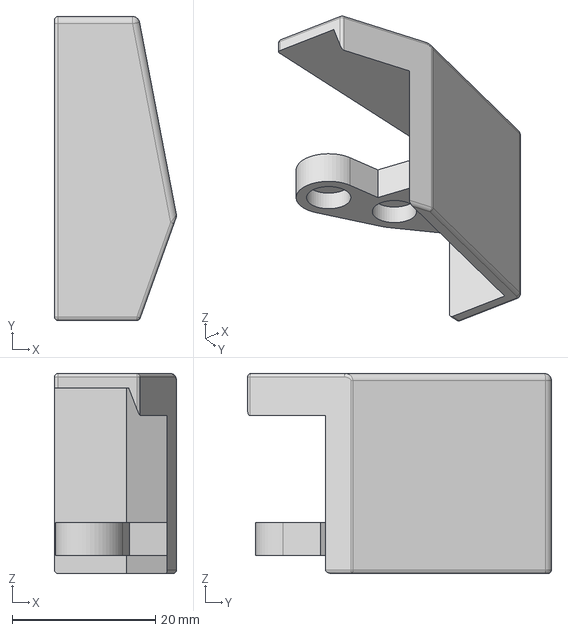
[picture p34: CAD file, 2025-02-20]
1.0/step/debug_cover.step
17.0 x 42.4 x 27.9 mm

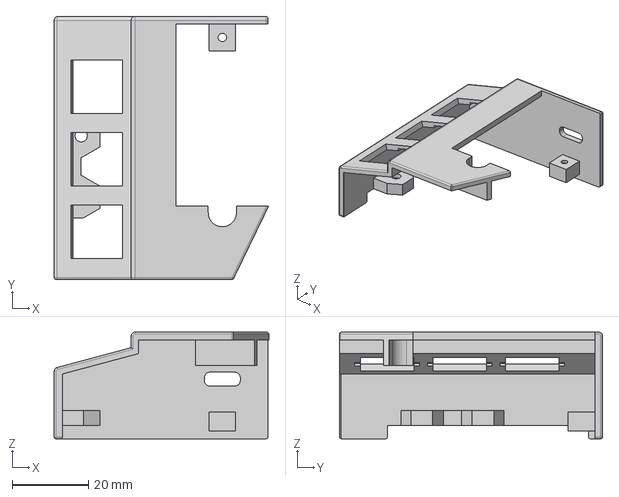
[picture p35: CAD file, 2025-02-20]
1.0/step/body_cover.step
56.3 x 69.1 x 28.0 mm

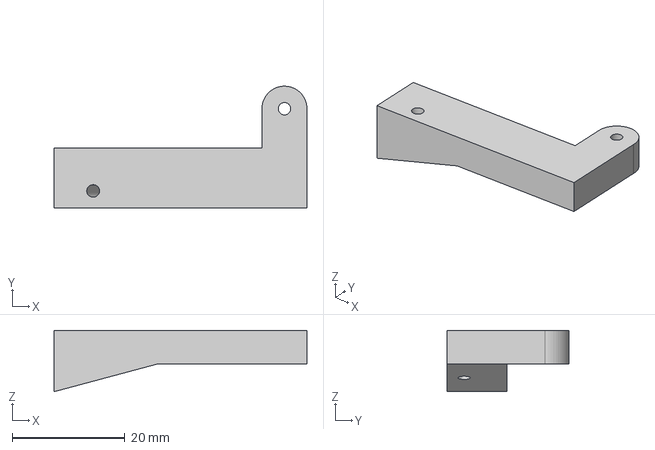
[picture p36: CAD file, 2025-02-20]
1.0/step/はんだ付け用治具1.step
44.9 x 21.6 x 10.9 mm

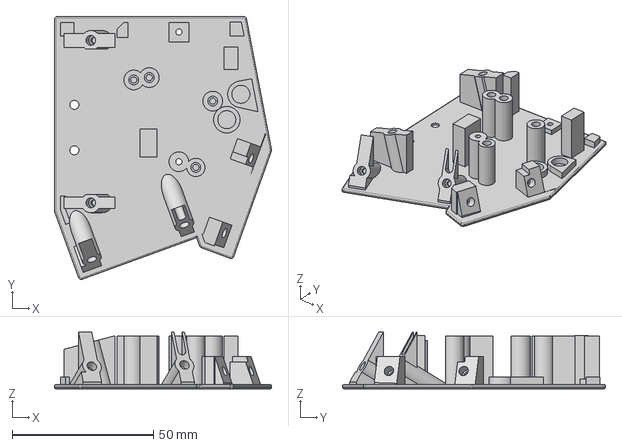
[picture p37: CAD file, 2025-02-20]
1.0/step/bottom.step
77.0 x 93.2 x 20.1 mm

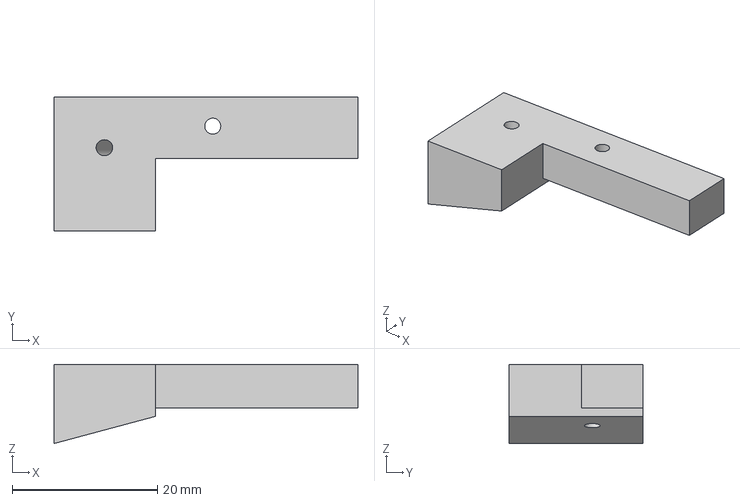
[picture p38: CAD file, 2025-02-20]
1.0/step/はんだ付け用治具2.step
41.9 x 18.4 x 10.9 mm

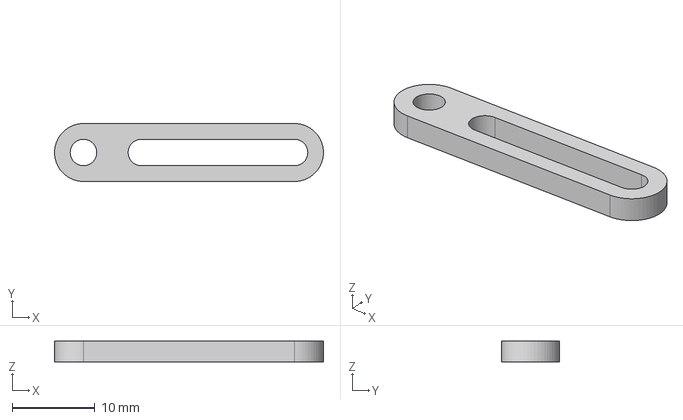
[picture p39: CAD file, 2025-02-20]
1.0/step/joint.step
32.5 x 7.00 x 2.50 mm

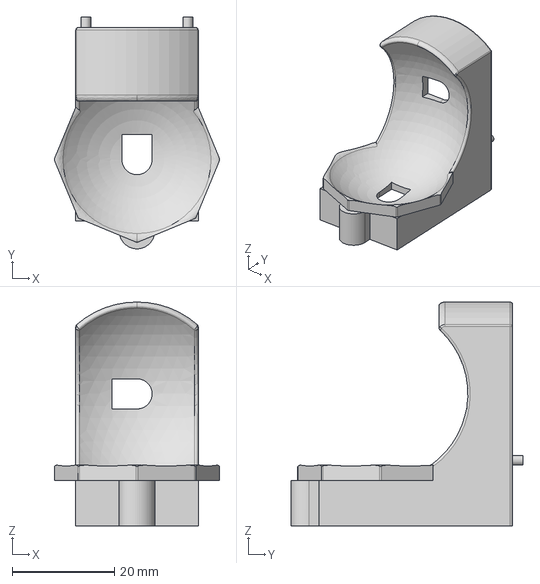
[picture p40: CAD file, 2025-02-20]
1.0/step/ball_holder.step
32.4 x 45.4 x 43.9 mm

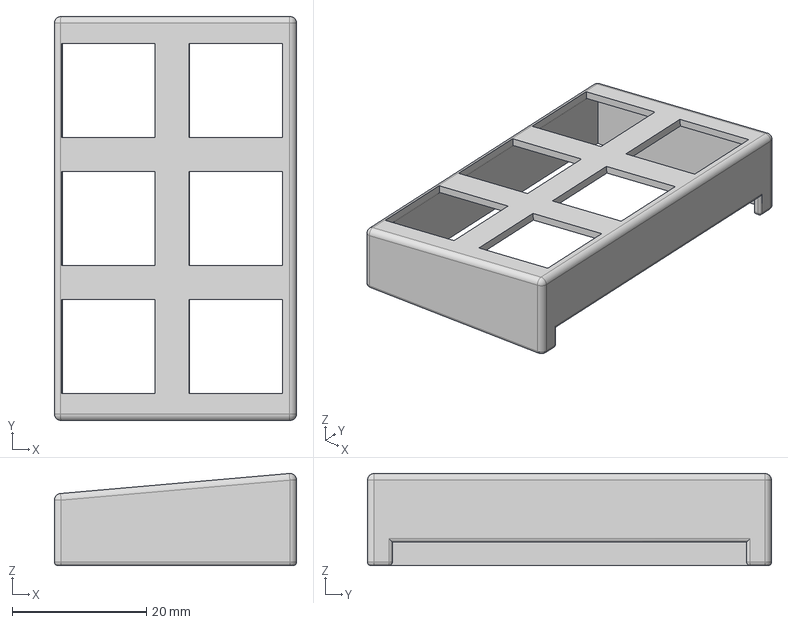
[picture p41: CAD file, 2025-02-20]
1.0/step/side_cover.step
36.1 x 60.1 x 13.7 mm

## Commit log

2025-02-17 ファイルを追加
2025-02-17 工具について記載(未完)
2025-02-17 メイン基板とサイドキーパッド基板の接続の項目を作成
2025-02-17 メイン，サイドキー基板の配線を記述
2025-02-18 とりあえず最後まで記述
2025-02-18 番号を追加
2025-02-18 目次を作成
2025-02-18 リンクエラーを修正
2025-02-18 調達先を追加
2025-02-19 組み立て以外の写真を追加
2025-02-19 不足していた図を追加
2025-02-19 図の一部編集
2025-02-19 stepのファイル名を追加
2025-02-20 名前をREADMEに変更
2025-02-20 フォルダ名を1.0に変更
2025-02-20 設計データを追加
    [10_OLED_module_2dpcb v17.GBL, 10_OLED_module_2dpcb v17.GBO, 10_OLED_module_2dpcb v17.GBP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]
2025-02-20 ディレクトリを変更
    [10_OLED_module_2dpcb v17.GBL, 10_OLED_module_2dpcb v17.GBO, 10_OLED_module_2dpcb v17.GBP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]
2025-02-20 READMEを配置
2025-02-20 READMEの内容を記述
2025-02-20 READMEのディレクトリを変更
2025-02-20 gitignoreを追加
2025-02-20 .vscodeを削除
2025-02-20 corret name
    [10_OLED_module_2dpcb v17.GBL, 10_OLED_module_2dpcb v17.GBO, 10_OLED_module_2dpcb v17.GBP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]
2025-02-22 buildguide.mdを削除
2025-02-22 CODEOWNERSファイルを追加
2025-02-22 CODEOWNERSのメンバーを更新
2025-03-24 40mmトラックボールが必要という記述を追加
2025-10-08 キーキャップの記述を追加、センサ向きの文言を修正
2025-10-09 パーツリストを作成、パーツに関する説明を追加
